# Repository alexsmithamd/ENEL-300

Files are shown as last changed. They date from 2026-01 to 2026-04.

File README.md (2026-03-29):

# ENEL-300
ENEL 300 Project Repo

This github repo will be used as the home of all project components. Code, CAD, general design work will be documented and stored here as well as one drive. 

### Guidelines
- Each module's directory contains a `pcb_design`, `print_3d_files`, and a `stm_code` sub-directory. Please organize your module's respective files in the correct directory. 

- The `print_3d_files` is NOT to be used for CAD files, but rather as an easy way to share STLs and slicer files so that we can effectively share the print workload amongst ourselves.

- **Avoid working in the same directory or on the same files as someone else - at the same time!!!** 
<br>
This can create "merge conflicts" which can be difficult to resolve.

Each module directory contains a `README.md` file. I would highly recommend putting **technical** documentation for your module in that file as it simplifies our workflow for everyone. Instead of having to look in OneDrive, one simply needs to do a `git pull` command to get the latest work and documentation!

Only use OneDrive for **administrative** documentation.

### Editing Markdown (.md) Files
Markdown is similar to LaTeX. It has very simple syntax and is used everywhere. **For editing, I would recommend VsCode with the following extension installed:**

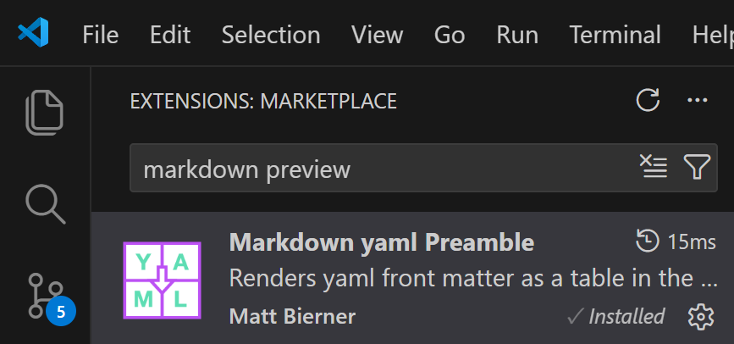
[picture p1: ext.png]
Optional title

<br>
This gives you the ability to edit and live preview your work as shown below:
<br>
<br>
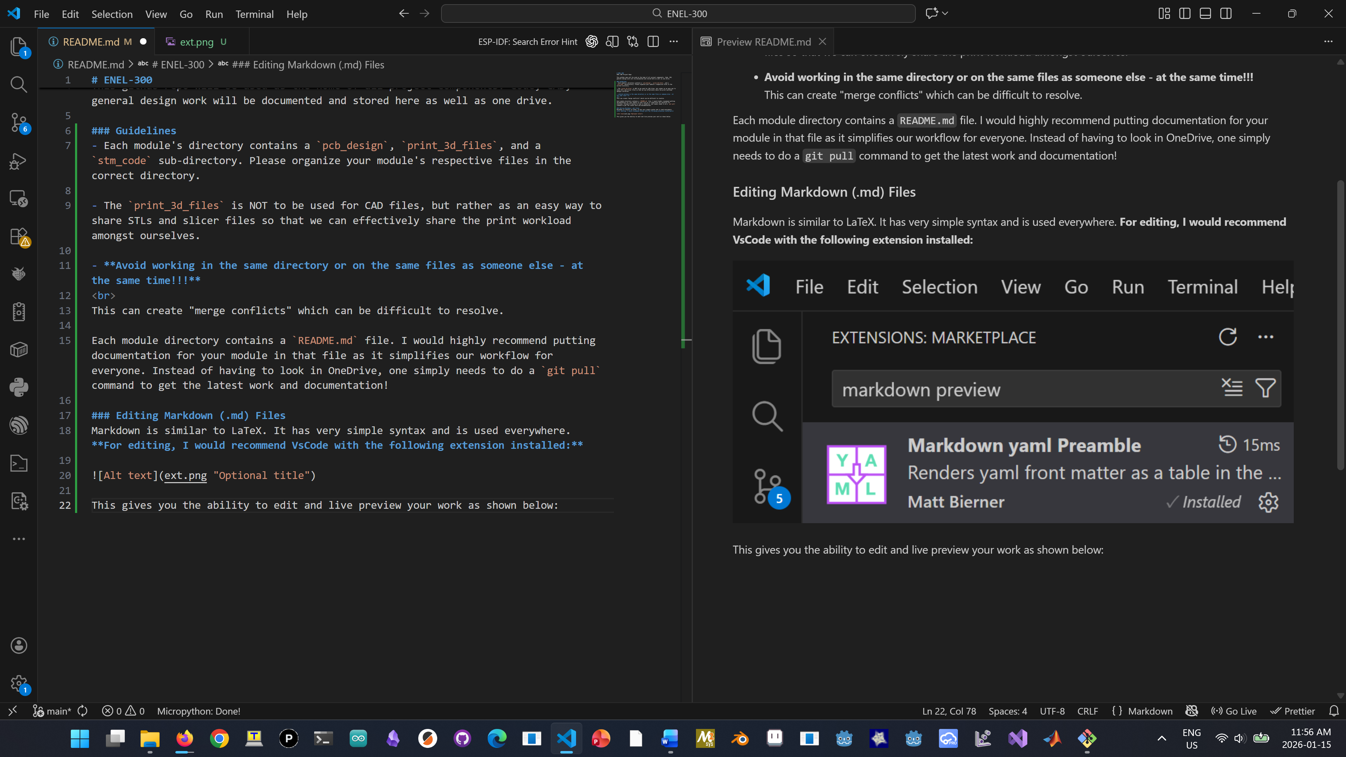
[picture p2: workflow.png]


### **To open the preview:** `Ctrl + Shift + P` then type `Markdown: Open Preview`

Drag the preview tab to the right pane and viola!

### Branches
Branches allow you to work on your own module without messing up somebody else's work. Changes you make in your own branch will NOT affect work done in another branch. Overtime, we will merge everyone's changes into the `main` branch. **DO NOT directly edit your work in the main branch.**  *The main branch is supposed to be the "working" version.* The division of a project into branches is unavoidable in industry.

I have created branches for each module.

1. Switching between branches<br>`git checkout main` -- switch to the main branch<br>`git checkout controller_board` -- switch to the controller_board branch

Commits and pushes will only apply to your respective branch. 

1. To view the current branch you are in
<br>`git branch`

### Pushing, Pulling, Adding, Committing
NOTE: A commit is like a snapshot of your project. You can revert your project back to any previous commits.
<br>
1. Whenever you want to work on the project, first sync your local repo with the remote repo (the one on GitHub):
<br>`git pull`

2. Before you plan to make major changes or upload your changes, *especially ones that may break your code:*
<br>`git add -A`
<br>`git commit -m "What ever message you want in these quotes"`

3. Uploading the latest commit<br>`git push`

<br>`git checkout -b controller_board origin/controller_board`

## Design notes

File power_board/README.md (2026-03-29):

# ENEL-300
### Power Board

# git
# Note

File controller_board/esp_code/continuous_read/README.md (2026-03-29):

<!-- @import "[TOC]" {cmd="toc" depthFrom=1 depthTo=6 orderedList=false} -->
| Supported Targets | ESP32 | ESP32-C3 | ESP32-C5 | ESP32-C6 | ESP32-C61 | ESP32-H2 | ESP32-P4 | ESP32-S2 | ESP32-S3 |
| --- | ----- | --- | --- | --- | --- | --- | --- | --- | --- |

# ADC DMA Example

(See the README.md file in the upper level 'examples' directory for more information about examples.)

This example shows how to use ADC Continuous Read Mode (DMA Mode) to read from GPIO pins via on-chip ADC module(s).

## How to use example

### Hardware Required

* A development board with ESP32, ESP32-S and ESP32-C SoC
* A USB cable for power supply and programming

Please refer to the `channel` array defined in `adc_dma_example_main.c`. These GPIOs should be connected to voltage sources (0 ~ 3.3V). If other ADC unit(s) / channel(s) are selected in your application,
feel free to modify these definitions.

### Configure the project

```
idf.py menuconfig
```

### Build and Flash

Build the project and flash it to the board, then run monitor tool to view serial output:

```
idf.py -p PORT flash monitor
```

(To exit the serial monitor, type ``Ctrl-]``.)

See the Getting Started Guide for full steps to configure and use ESP-IDF to build projects.

## Example Output

Running this example, you will see the following log output on the serial monitor:
```
I (367) EXAMPLE: adc_pattern[0].atten is :0
I (377) EXAMPLE: adc_pattern[0].channel is :2
I (377) EXAMPLE: adc_pattern[0].unit is :0
I (387) EXAMPLE: adc_pattern[1].atten is :0
I (387) EXAMPLE: adc_pattern[1].channel is :3
I (397) EXAMPLE: adc_pattern[1].unit is :0
I (397) gpio: GPIO[3]| InputEn: 0| OutputEn: 0| OpenDrain: 0| Pullup: 0| Pulldown: 0| Intr:0
I (407) gpio: GPIO[4]| InputEn: 0| OutputEn: 0| OpenDrain: 0| Pullup: 0| Pulldown: 0| Intr:0
I (417) TASK: ret is 0, ret_num is 256
I (427) EXAMPLE: Unit: ADC-1, Channel: 2, Value: 819
I (427) EXAMPLE: Unit: ADC-1, Channel: 3, Value: 7b9
I (437) EXAMPLE: Unit: ADC-1, Channel: 2, Value: 7ab
I (437) EXAMPLE: Unit: ADC-1, Channel: 3, Value: 74b
I (447) EXAMPLE: Unit: ADC-1, Channel: 2, Value: 74d
I (447) EXAMPLE: Unit: ADC-1, Channel: 3, Value: 6e5
I (457) EXAMPLE: Unit: ADC-1, Channel: 2, Value: 6ee
I (467) EXAMPLE: Unit: ADC-1, Channel: 3, Value: 680
I (467) EXAMPLE: Unit: ADC-1, Channel: 2, Value: 69a
I (477) EXAMPLE: Unit: ADC-1, Channel: 3, Value: 62f
...
```

## Troubleshooting

* program upload failure

    * Hardware connection is not correct: run `idf.py -p PORT monitor`, and reboot your board to see if there are any output logs.
    * The baud rate for downloading is too high: lower your baud rate in the `menuconfig` menu, and try again.

For any technical queries, please open an [issue](https://github.com/espressif/esp-idf/issues) on GitHub. We will get back to you soon.

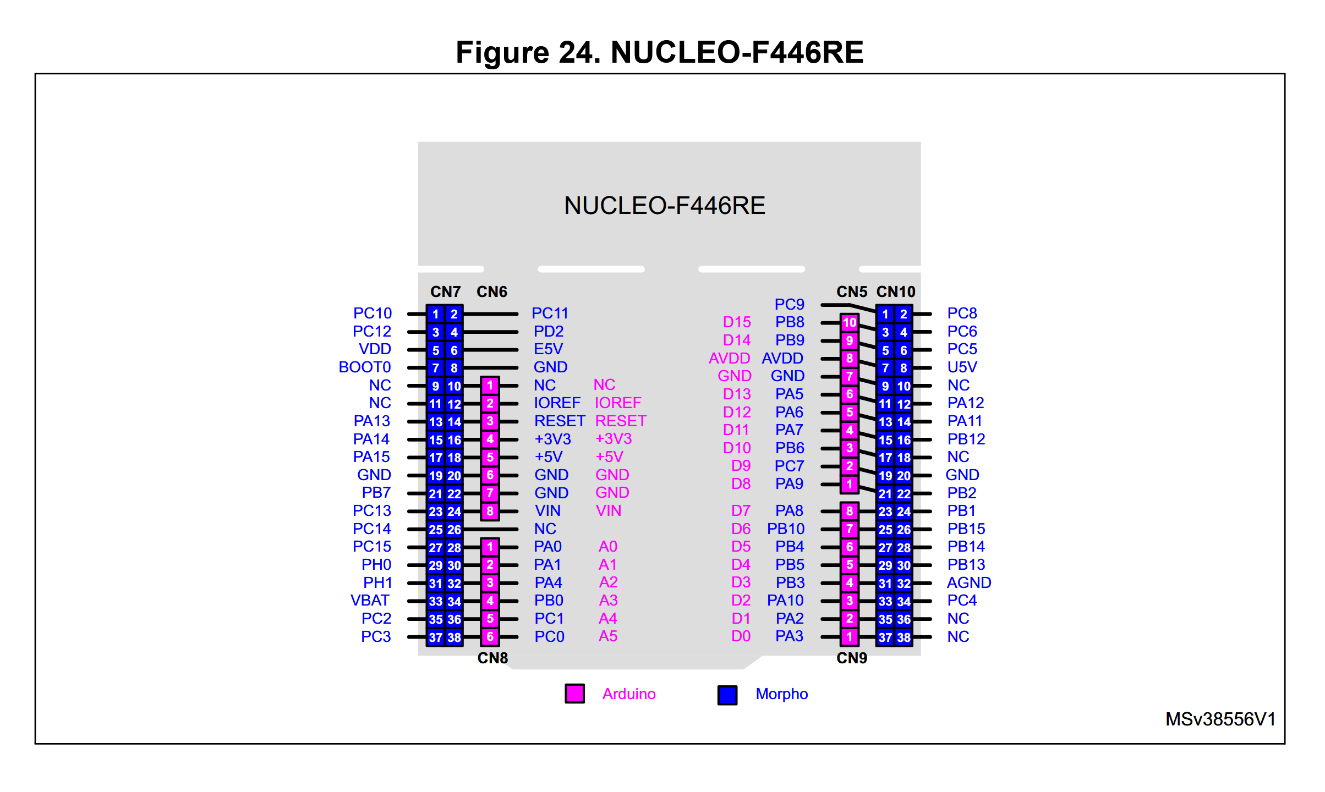
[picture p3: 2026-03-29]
controller_board/stm_board_pinout.png

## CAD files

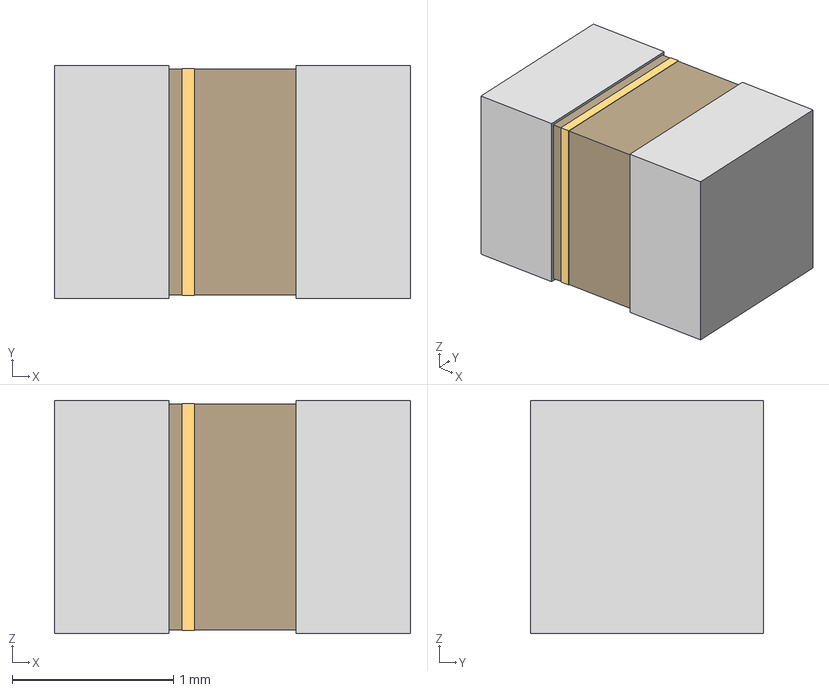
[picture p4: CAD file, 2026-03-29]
power_board/pcb_design/component_downloads/GRM21BR61E226ME44L/Altium/GRM21BR61E226ME44L/CAP_GRM21_MUR.step
2.21 x 1.45 x 1.45 mm

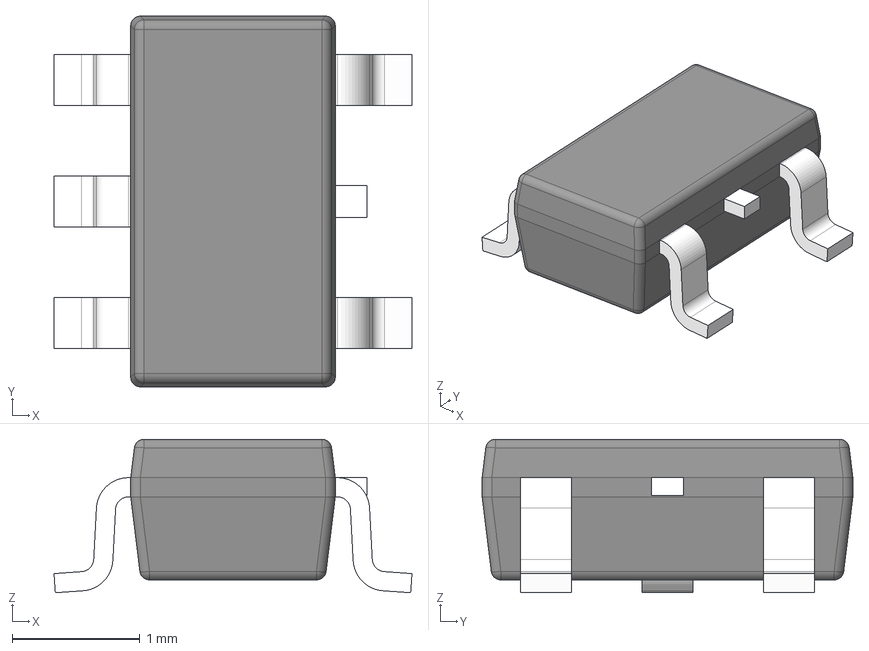
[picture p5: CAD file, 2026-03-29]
power_board/pcb_design/component_downloads/ul_TLV75733PDBVR/DBV0005A.stp
2.80 x 2.90 x 1.20 mm
BODY-SOT
LEAD-SOT x 5
LEAD-DUMMY

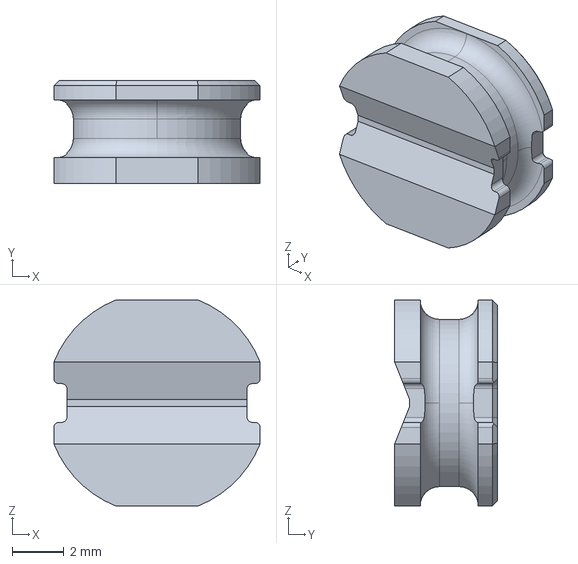
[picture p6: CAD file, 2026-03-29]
power_board/pcb_design/component_downloads/SRN8040_3R3Y/7435157.stp
8.00 x 4.00 x 8.00 mm

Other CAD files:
power_board/pcb_design/component_downloads/GRM21BR61E226ME44L/CAP_GRM21_MUR.step

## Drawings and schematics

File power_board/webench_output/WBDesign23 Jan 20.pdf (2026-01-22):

## WEBENCH ® Design Report

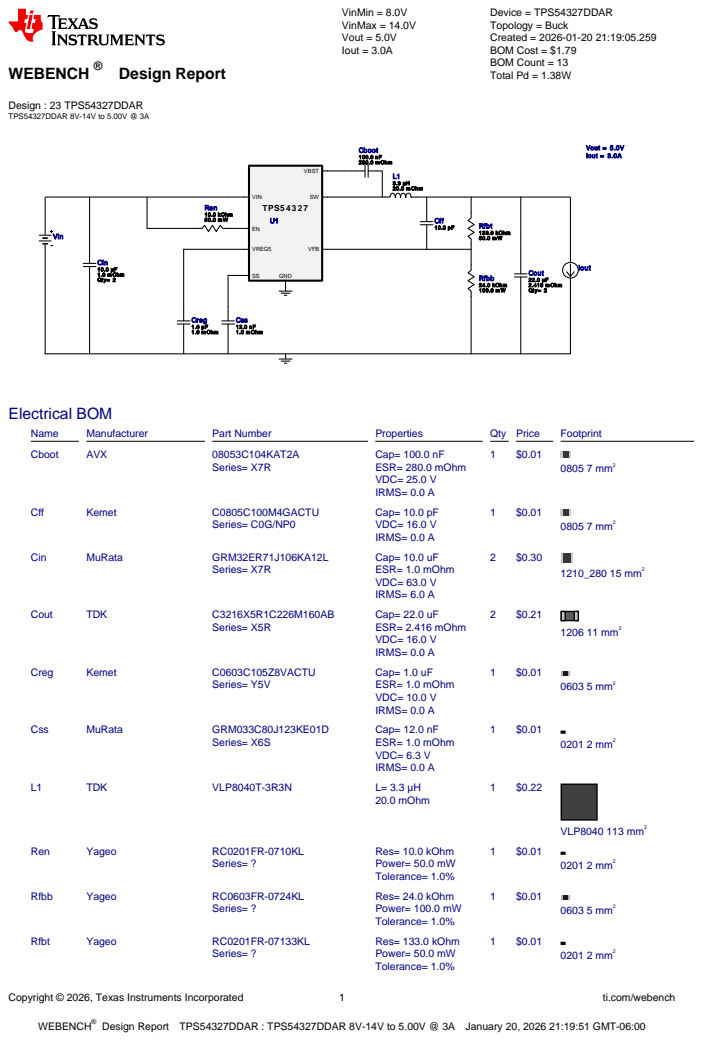
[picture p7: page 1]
Copyright © 2026, Texas Instruments Incorporated; ti.com/webench; WEBENCH®; Design : 23 TPS54327DDAR TPS54327DDAR 8V-14V to 5.00V @ 3A; VinMin = 8.0V VinMax = 14.0V Vout = 5.0V Iout = 3.0A; Device = TPS54327DDAR Topology = Buck Created = 2026-01-20 21:19:05.259 BOM Cost = $1.79 BOM Count = 13 Total Pd = 1.38W; Rfbb 24.0 kOhm 100.0 m W; Cout 22.0 µF 2.416 m Ohm Qty= 2; Css 12.0 nF 1.0 m Ohm; Ren 10.0 kOhm 50.0 m W; Creg 1.0 µF 1.0 m Ohm; Vout = 5.0V Iout = 3.0A Cboot 100.0 nF 280.0 m Ohm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

Design Report TPS54327DDAR : TPS54327DDAR 8V-14V to 5.00V @ 3A January 20, 2026 21:19:51 GMT-06:00

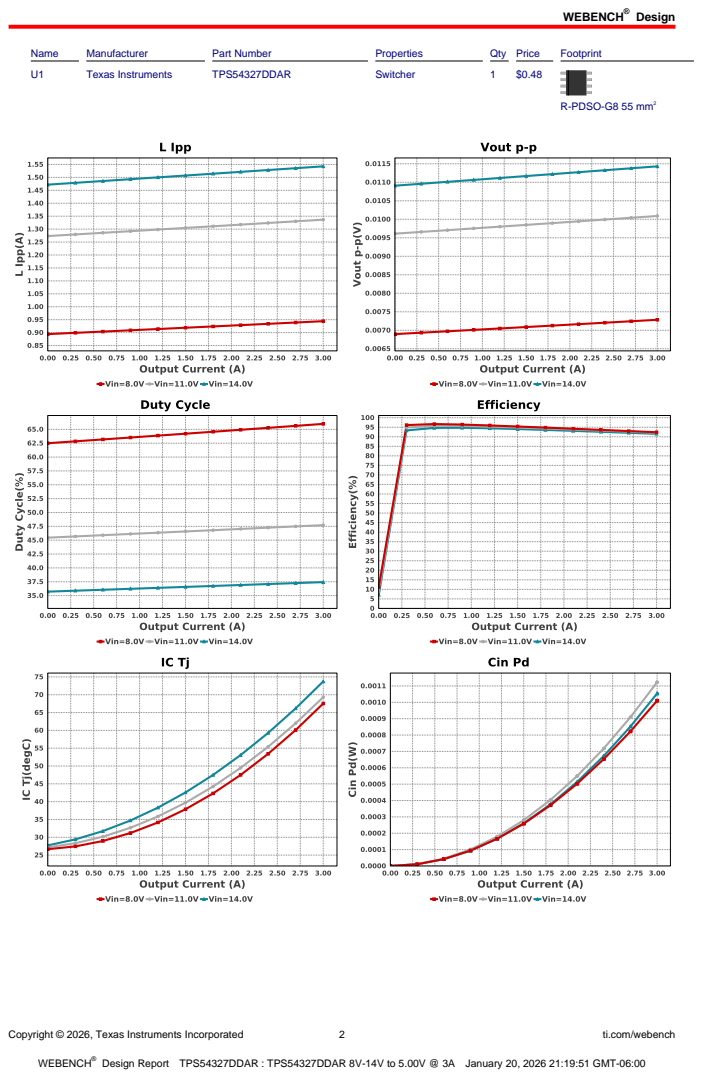
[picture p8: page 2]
Design; Copyright © 2026, Texas Instruments Incorporated; ti.com/webench; Name; Manufacturer; Part Number; Properties; Qty Price; Footprint; Texas Instruments; TPS54327DDAR; Switcher; R-PDSO-G8 55 mm²

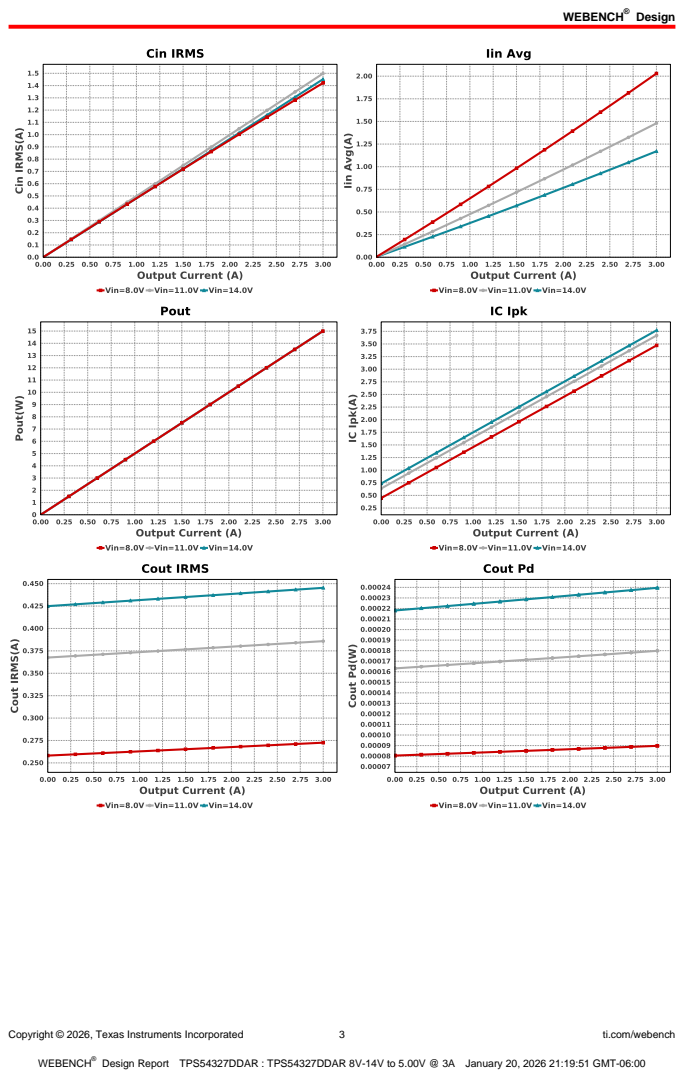
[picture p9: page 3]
Copyright © 2026, Texas Instruments Incorporated; ti.com/webench

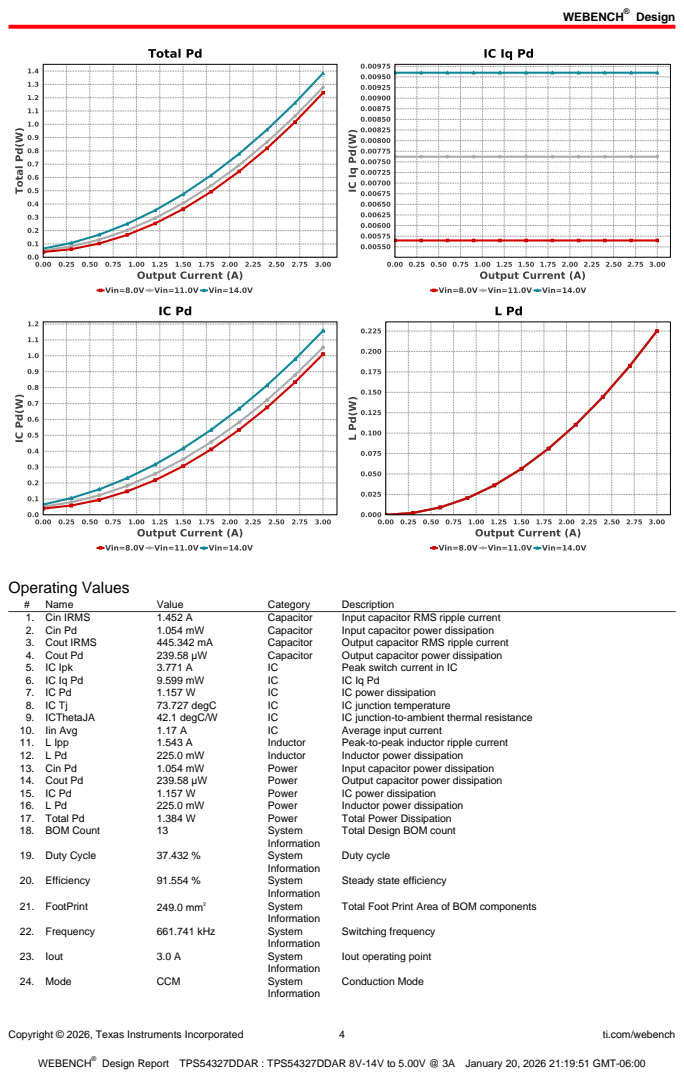
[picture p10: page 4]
Copyright © 2026, Texas Instruments Incorporated; ti.com/webench; Operating Values; Name; Value; Category; Description; 1. Cin IRMS; Capacitor; Input capacitor RMS ripple current; 2. Cin Pd; Input capacitor power dissipation; 3. Cout IRMS; Output capacitor RMS ripple current; 4. Cout Pd; Output capacitor power dissipation; 5. IC Ipk; Peak switch current in IC; IC power dissipation; 73.727 degC; IC junction temperature; 9. ICThetaJA; 42.1 degC/W; IC junction-to-ambient thermal resistance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

Total Design BOM count

Steady state efficiency

Total Foot Print Area of BOM components

Iout operating point

Copyright © 2026, Texas Instruments Incorporated | 5 | ti.com/webench
# | Name | Value | Category | Description

25. Pout | 15.0 W | System
| | | Information | Total output power
26. Total BOM | $1.79 | System
| | | Information | Total BOM Cost
27. Vin | 14.0 V | System
| | | Information | Vin operating point
28. Vout | 5.0 V | System
| | | Information | Operational Output Voltage
29. Vout Actual | 5.004 V | System
| | | Information | Vout Actual calculated based on selected voltage divider resistors
30. Vout Tolerance | 3.573 % | System
| | | Information | Vout Tolerance based on IC Tolerance (no load) and voltage divider resistors if applicable
31. Vout p-p | 11.431 mV | System
| | | Information | Peak-to-peak output ripple voltage

## Design Inputs

Name | Value | Description
Iout | 3.0 | Maximum Output Current
SoftStart | 5.0 ms | Soft Start Time (ms)
VinMax | 14.0 | Maximum input voltage
VinMin | 8.0 | Minimum input voltage
Vout | 5.0 | Output Voltage
| base_pn | | TPS54327 | Base Product Number
source | DC | Input Source Type
Ta | 25.0 | Ambient temperature


Copyright © 2026, Texas Instruments Incorporated | 6 | ti.com/webench

## Assembly

## Component Testing

Some published data on components in datasheets such as Capacitor ESR and Inductor DC resistance is based on conservative values that will guarantee that the components always exceed the specification. For design purposes it is usually better to work with typical values. Since this data is not always available it is a good practice to measure the Capacitance and ESR values of Cin and Cout, and the inductance and DC resistance of L1 before assembly of the board. Any large discrepancies in values should be electrically simulated in WEBENCH to check for instabilities and thermally simulated in WebTHERM to make sure critical temperatures are not exceeded.

## Soldering Component to Board

If board assembly is done in house it is best to tack down one terminal of a component on the board then solder the other terminal. For surface mount parts with large tabs, such as the DPAK, the tab on the back of the package should be pre-tinned with solder, then tacked into place by one of the pins. To solder the tab town to the board place the iron down on the board while resting against the tab, heating both surfaces simultaneously. Apply light pressure to the top of the plastic case until the solder flows around the part and the part is flush with the PCB. If the solder is not flowing around the board you may need a higher wattage iron (generally 25W to 30W is enough).
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

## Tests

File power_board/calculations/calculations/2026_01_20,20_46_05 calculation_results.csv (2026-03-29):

name | values
soft start T | 5.049
top resistor R | 122344.44444444444
cap rms I | 0.4016815416439882
L pk-pk I | 1.3914656771799627
L max pk I | 3.6957328385899815
L rms I | 3.0267718878200074

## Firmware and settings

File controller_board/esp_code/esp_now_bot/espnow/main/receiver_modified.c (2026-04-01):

/* ESPNOW Example

   This example code is in the Public Domain (or CC0 licensed, at your option.)

   Unless required by applicable law or agreed to in writing, this
   software is distributed on an "AS IS" BASIS, WITHOUT WARRANTIES OR
   CONDITIONS OF ANY KIND, either express or implied.
*/

/*
   This example shows how to use ESPNOW.
   Prepare two device, one for sending ESPNOW data and another for receiving
   ESPNOW data.
*/
#include <stdlib.h>
#include <math.h>
#include <time.h>
#include <complex.h>
#include <string.h>
#include <assert.h>
#include "freertos/FreeRTOS.h"
#include "freertos/semphr.h"
#include "freertos/timers.h"
#include "nvs_flash.h"
#include "esp_random.h"
#include "esp_event.h"
#include "esp_netif.h"
#include "esp_wifi.h"
#include "esp_log.h"
#include "esp_mac.h"
#include "esp_now.h"
#include "esp_crc.h"
#include "espnow_example.h"


#include "esp_timer.h"
#include "driver/gpio.h"
#include <driver/ledc.h>

#define L_Y_OFFSET 1.56
#define R_X_OFFSET 1.59

// these are the direction pins
#define IN1 GPIO_NUM_7
#define IN2 GPIO_NUM_6
#define IN3 GPIO_NUM_5
#define IN4 GPIO_NUM_4


#define PWM_1_CHANNEL LEDC_CHANNEL_0
#define PWM_2_CHANNEL LEDC_CHANNEL_1
#define PWM_3_CHANNEL LEDC_CHANNEL_2
#define PWM_4_CHANNEL LEDC_CHANNEL_3

         
#define LEDC_CHANNEL LEDC_CHANNEL_0
#define LEDC_TIMER LEDC_TIMER_0
#define LEDC_MODE LEDC_LOW_SPEED_MODE
#define LEDC_DUTY_RES LEDC_TIMER_10_BIT // 10-bit resolution (0-1023)
#define LEDC_FREQUENCY 3000   

#define US_TRIG_PIN   GPIO_NUM_17
#define US_ECHO_PIN   GPIO_NUM_18

//  Tuning knobs 
#define SOUND_CM_PER_US  0.0343f
#define PULSE_ON_US    8//70//20//1            // ms coil is at high state
#define PULSE_OFF_US   14//130//80            // ms coil is LOW state
#define SAMPLES_PER_MEAS  400//200        // more samples = less noise, slower response based off mapleaf config
// timeouts
#define ECHO_RISE_TIMEOUT_US   50000   // 30 ms (covers > 5m, but safe)
#define ECHO_FALL_TIMEOUT_US   50000
#define BASELINE_MS    1500//1500          // baseline averaging time on boot
#define THRESHOLD      18//10            // ADC counts; adjust after you see readings

#define HEADLIGHT_GPIO GPIO_NUM_10
#define METAL_DETECT GPIO_NUM_11

int trim_r = 0;
int trim_l = 0;

typedef struct {
    float raw[4];
} adc_snap_t;

adc_snap_t adc_struct = {{-1.0, -1.0, -1.0, -1.0}};

static float g_ultrasonic_cm = -1.0f;
static portMUX_TYPE g_ultrasonic_mux = portMUX_INITIALIZER_UNLOCKED;

#define ESPNOW_MAXDELAY 512

static const char *TAG = "espnow_example";

static QueueHandle_t s_example_espnow_queue = NULL;

// mac address of the master <-_-> dc:b4:d9:09:f9:80
static uint8_t s_peer_mac[ESP_NOW_ETH_ALEN] = { 0xDC, 0xB4, 0xD9, 0x0b, 0x64, 0x5c };
static uint8_t s_example_broadcast_mac[ESP_NOW_ETH_ALEN] = { 0xDC, 0xB4, 0xD9, 0x0b, 0x64, 0x5c };
static uint16_t s_example_espnow_seq[EXAMPLE_ESPNOW_DATA_MAX] = { 0, 0 };

static void example_espnow_deinit(example_espnow_send_param_t *send_param);


int map(double x, double in_min, double in_max, int out_min, int out_max) {
  return (x - in_min) * (out_max - out_min) / (in_max - in_min) + out_min;
}

// ultrasonic code

static void ultrasonic_init(void) {
    gpio_reset_pin(US_TRIG_PIN);
    gpio_set_direction(US_TRIG_PIN, GPIO_MODE_OUTPUT);
    gpio_set_level(US_TRIG_PIN, 0);

    gpio_reset_pin(US_ECHO_PIN);
    gpio_set_direction(US_ECHO_PIN, GPIO_MODE_INPUT);
}

static int64_t pulse_in_us(gpio_num_t pin, int level, int64_t timeout_us) {
    int64_t start = esp_timer_get_time();
    while (gpio_get_level(pin) != level) {
        if ((esp_timer_get_time() - start) > timeout_us) return -1;
    }
    int64_t t0 = esp_timer_get_time();
    while (gpio_get_level(pin) == level) {
        if ((esp_timer_get_time() - t0) > timeout_us) return -1;
    }
    return esp_timer_get_time() - t0;
}

static float ultrasonic_read_cm(void) {

    // Ensure low
    gpio_set_level(US_TRIG_PIN, 0);
    esp_rom_delay_us(2);

    // 10us trigger pulse
    gpio_set_level(US_TRIG_PIN, 1);
    esp_rom_delay_us(10);
    gpio_set_level(US_TRIG_PIN, 0);

    // Wait for echo HIGH then measure HIGH width
    // First wait for rising edge (echo goes high)
    int64_t start = esp_timer_get_time();
    while (gpio_get_level(US_ECHO_PIN) == 0) {
        if (esp_timer_get_time() - start > ECHO_RISE_TIMEOUT_US) return -1.0f;
    }

    // Now measure high pulse width
    int64_t width = pulse_in_us(US_ECHO_PIN, 1, ECHO_FALL_TIMEOUT_US);
    if (width < 0) return -1.0f;

    // distance = (time * speed) / 2
    float cm = (width * SOUND_CM_PER_US) / 2.0f;
    return cm;
}


/* WiFi should start before using ESPNOW */
static void example_wifi_init(void)
{
    ESP_ERROR_CHECK(esp_netif_init());
    ESP_ERROR_CHECK(esp_event_loop_create_default());
    wifi_init_config_t cfg = WIFI_INIT_CONFIG_DEFAULT();
    ESP_ERROR_CHECK( esp_wifi_init(&cfg) );
    ESP_ERROR_CHECK( esp_wifi_set_storage(WIFI_STORAGE_RAM) );
    ESP_ERROR_CHECK( esp_wifi_set_mode(ESPNOW_WIFI_MODE) );
    ESP_ERROR_CHECK( esp_wifi_start());
    ESP_ERROR_CHECK( esp_wifi_set_channel(CONFIG_ESPNOW_CHANNEL, WIFI_SECOND_CHAN_NONE));

#if CONFIG_ESPNOW_ENABLE_LONG_RANGE
    ESP_ERROR_CHECK( esp_wifi_set_protocol(ESPNOW_WIFI_IF, WIFI_PROTOCOL_11B|WIFI_PROTOCOL_11G|WIFI_PROTOCOL_11N|WIFI_PROTOCOL_LR) );
#endif
}

/* ESPNOW sending or receiving callback function is called in WiFi task.
 * Users should not do lengthy operations from this task. Instead, post
 * necessary data to a queue and handle it from a lower priority task. */
static void example_espnow_send_cb(const esp_now_send_info_t *tx_info, esp_now_send_status_t status)
{
    example_espnow_event_t evt;
    example_espnow_event_send_cb_t *send_cb = &evt.info.send_cb;

    if (tx_info == NULL) {
        ESP_LOGE(TAG, "Send cb arg error");
        return;
    }

    evt.id = EXAMPLE_ESPNOW_SEND_CB;
    memcpy(send_cb->mac_addr, tx_info->des_addr, ESP_NOW_ETH_ALEN);
    send_cb->status = status;
    if (xQueueSend(s_example_espnow_queue, &evt, ESPNOW_MAXDELAY) != pdTRUE) {
        ESP_LOGW(TAG, "Send send queue fail");
    }
}

static void example_espnow_recv_cb(const esp_now_recv_info_t *recv_info, const uint8_t *data, int len)
{
    example_espnow_event_t evt;
    example_espnow_event_recv_cb_t *recv_cb = &evt.info.recv_cb;
    uint8_t * mac_addr = recv_info->src_addr;
    uint8_t * des_addr = recv_info->des_addr;

    if (mac_addr == NULL || data == NULL || len <= 0) {
        ESP_LOGE(TAG, "Receive cb arg error");
        return;
    }

    if (IS_BROADCAST_ADDR(des_addr)) {
        /* If added a peer with encryption before, the receive packets may be
         * encrypted as peer-to-peer message or unencrypted over the broadcast channel.
         * Users can check the destination address to distinguish it.
         */
        ESP_LOGD(TAG, "Receive broadcast ESPNOW data");
    } else {
        ESP_LOGD(TAG, "Receive unicast ESPNOW data");
    }

    evt.id = EXAMPLE_ESPNOW_RECV_CB;
    memcpy(recv_cb->mac_addr, mac_addr, ESP_NOW_ETH_ALEN);
    recv_cb->data = malloc(len);
    if (recv_cb->data == NULL) {
        ESP_LOGE(TAG, "Malloc receive data fail");
        return;
    }
    memcpy(recv_cb->data, data, len);
    recv_cb->data_len = len;
    if (xQueueSend(s_example_espnow_queue, &evt, ESPNOW_MAXDELAY) != pdTRUE) {
        ESP_LOGW(TAG, "Send receive queue fail");
        free(recv_cb->data);
    }
}

/* Parse received ESPNOW data. */

// lock
static portMUX_TYPE adc_struct_mux = portMUX_INITIALIZER_UNLOCKED; 

int light_state = 0;

int example_espnow_data_parse(uint8_t *data, uint16_t data_len, uint8_t *state, uint16_t *seq, uint32_t *magic)
{
    example_espnow_data_t *buf = (example_espnow_data_t *)data;
    uint16_t crc, crc_cal = 0;

    if (data_len < sizeof(example_espnow_data_t)) {
        ESP_LOGE(TAG, "Receive ESPNOW data too short, len:%d", data_len);
        return -1;
    }

    *state = buf->state;
    *seq = buf->seq_num;
    *magic = buf->magic;
    crc = buf->crc;
    buf->crc = 0;
    crc_cal = esp_crc16_le(UINT16_MAX, (uint8_t const *)buf, data_len);

    float temp_arr [7] = {-1.0, -1.0, -1.0, -1.0, -1.0, -1.0, -1.0}; // last two are trim params
    memcpy(temp_arr, buf->payload, sizeof(temp_arr));
    light_state = (int)temp_arr[4];
    trim_l = (int)temp_arr[5];
    trim_r = (int)temp_arr[6];

    gpio_set_level(HEADLIGHT_GPIO, light_state);

    float control_data[4] = {-1.0, -1.0, -1.0, -1.0};
    memcpy(control_data, temp_arr, sizeof(temp_arr) - 3); // copy the first four elements
   
    adc_snap_t temp = {{-1.0, -1.0, -1.0, -1.0}}; // kind of forgot what the purpose of this is
    memcpy(temp.raw, control_data, sizeof(control_data));

    taskENTER_CRITICAL(&adc_struct_mux);
        adc_struct = temp;
    taskEXIT_CRITICAL(&adc_struct_mux);

    //ESP_LOGI("RECIEVED ADC DATA", "%f %f %f %f", temp.raw[0], temp.raw[1], temp.raw[2], temp.raw[3]);

    if (crc_cal == crc) {
        return buf->type;
    }

    return -1;
}
void example_espnow_data_prepare(example_espnow_send_param_t *send_param)
{
    example_espnow_data_t *buf = (example_espnow_data_t *)send_param->buffer;

    assert(send_param->len >= sizeof(example_espnow_data_t));

    buf->type = IS_BROADCAST_ADDR(send_param->dest_mac) ? EXAMPLE_ESPNOW_DATA_BROADCAST : EXAMPLE_ESPNOW_DATA_UNICAST;
    buf->state = send_param->state;
    buf->seq_num = s_example_espnow_seq[buf->type]++;
    buf->crc = 0;
    buf->magic = send_param->magic;

    // Clear payload first
    memset(buf->payload, 0, send_param->len - sizeof(example_espnow_data_t));

    // Copy ultrasonic reading into payload
    float ultrasonic_cm;
    taskENTER_CRITICAL(&g_ultrasonic_mux);
    ultrasonic_cm = g_ultrasonic_cm;
    taskEXIT_CRITICAL(&g_ultrasonic_mux);

    int metal_state = gpio_get_level(METAL_DETECT);

    float combined_pay[2] = {-1.0, -1.0};
    combined_pay[0] = ultrasonic_cm; 
    combined_pay[1] = (float)metal_state;

    memcpy(buf->payload, combined_pay, sizeof(combined_pay));

    buf->crc = esp_crc16_le(UINT16_MAX, (uint8_t const *)buf, send_param->len);
}




static void ultrasonic_tx_task(void *arg)
{
    example_espnow_send_param_t *send_param = (example_espnow_send_param_t *)arg;
    assert(send_param != NULL);

    ESP_LOGI(TAG, "Ultrasonic TX task started");

    while (1) {
        example_espnow_data_prepare(send_param);
        esp_err_t err = esp_now_send(send_param->dest_mac, send_param->buffer, send_param->len);
        if (err != ESP_OK) {
            ESP_LOGW(TAG, "ultrasonic esp_now_send failed: %s", esp_err_to_name(err));
        }
        vTaskDelay(pdMS_TO_TICKS(100));
    }
}


static void example_espnow_task(void *pvParameter)
{
    example_espnow_event_t evt;
    uint8_t recv_state = 0;
    uint16_t recv_seq = 0;
    uint32_t recv_magic = 0;
    int ret;

    (void)pvParameter;
    ESP_LOGI(TAG, "Robot RX task started");

    while (xQueueReceive(s_example_espnow_queue, &evt, portMAX_DELAY) == pdTRUE) {

        switch (evt.id) {
            case EXAMPLE_ESPNOW_SEND_CB:
            {
                example_espnow_event_send_cb_t *send_cb = &evt.info.send_cb;
                ESP_LOGD(TAG, "Send callback from " MACSTR ", status=%d",
                         MAC2STR(send_cb->mac_addr), send_cb->status);
                break;
            }

            case EXAMPLE_ESPNOW_RECV_CB:
            {
                example_espnow_event_recv_cb_t *recv_cb = &evt.info.recv_cb;

                ret = example_espnow_data_parse(recv_cb->data, recv_cb->data_len,
                                                &recv_state, &recv_seq, &recv_magic);

                if (ret == EXAMPLE_ESPNOW_DATA_UNICAST) {
                    ESP_LOGD(TAG, "Received unicast from " MACSTR ", len=%d",
                             MAC2STR(recv_cb->mac_addr), recv_cb->data_len);
                } else if (ret < 0) {
                    ESP_LOGW(TAG, "Receive parse error from " MACSTR, MAC2STR(recv_cb->mac_addr));
                }

                free(recv_cb->data);
                break;

            }
            default:
                ESP_LOGE(TAG, "Callback type error: %d", evt.id);
                break;
        }
    }
}

static esp_err_t example_espnow_init(void)
{
    example_espnow_send_param_t *send_param;

    s_example_espnow_queue = xQueueCreate(ESPNOW_QUEUE_SIZE, sizeof(example_espnow_event_t));
    if (s_example_espnow_queue == NULL) {
        ESP_LOGE(TAG, "Create queue fail");
        return ESP_FAIL;
    }

    /* Initialize ESPNOW and register sending and receiving callback function. */
    ESP_ERROR_CHECK( esp_now_init() );
    ESP_ERROR_CHECK( esp_now_register_send_cb(example_espnow_send_cb) );
    ESP_ERROR_CHECK( esp_now_register_recv_cb(example_espnow_recv_cb) );
#if CONFIG_ESPNOW_ENABLE_POWER_SAVE
    ESP_ERROR_CHECK( esp_now_set_wake_window(CONFIG_ESPNOW_WAKE_WINDOW) );
    ESP_ERROR_CHECK( esp_wifi_connectionless_module_set_wake_interval(CONFIG_ESPNOW_WAKE_INTERVAL) );
#endif
    /* Set primary master key. */
    ESP_ERROR_CHECK( esp_now_set_pmk((uint8_t *)CONFIG_ESPNOW_PMK) );

    /* Add broadcast peer information to peer list. */
    esp_now_peer_info_t *peer = malloc(sizeof(esp_now_peer_info_t));
    if (peer == NULL) {
        ESP_LOGE(TAG, "Malloc peer information fail");
        vQueueDelete(s_example_espnow_queue);
        s_example_espnow_queue = NULL;
        esp_now_deinit();
        return ESP_FAIL;
    }
    memset(peer, 0, sizeof(esp_now_peer_info_t));
    peer->channel = CONFIG_ESPNOW_CHANNEL;
    peer->ifidx = ESPNOW_WIFI_IF;
    peer->encrypt = false;
    memcpy(peer->peer_addr, s_peer_mac, ESP_NOW_ETH_ALEN);
    ESP_ERROR_CHECK( esp_now_add_peer(peer) );
    free(peer);

    /* Initialize sending parameters. */
    send_param = malloc(sizeof(example_espnow_send_param_t));
    if (send_param == NULL) {
        ESP_LOGE(TAG, "Malloc send parameter fail");
        vQueueDelete(s_example_espnow_queue);
        s_example_espnow_queue = NULL;
        esp_now_deinit();
        return ESP_FAIL;
    }
    memset(send_param, 0, sizeof(example_espnow_send_param_t));
    send_param->unicast = true;
    send_param->broadcast = false;
    send_param->state = 0;
    send_param->magic = esp_random();
    send_param->count = CONFIG_ESPNOW_SEND_COUNT;
    send_param->delay = CONFIG_ESPNOW_SEND_DELAY;
    send_param->len = CONFIG_ESPNOW_SEND_LEN;
    send_param->buffer = malloc(CONFIG_ESPNOW_SEND_LEN);
    if (send_param->buffer == NULL) {
        ESP_LOGE(TAG, "Malloc send buffer fail");
        free(send_param);
        vQueueDelete(s_example_espnow_queue);
        s_example_espnow_queue = NULL;
        esp_now_deinit();
        return ESP_FAIL;
    }
    memcpy(send_param->dest_mac, s_peer_mac, ESP_NOW_ETH_ALEN);
    example_espnow_data_prepare(send_param);


    xTaskCreatePinnedToCore(example_espnow_task, "robot_rx_task", 4096, NULL, 6, NULL, 0);
    xTaskCreatePinnedToCore(ultrasonic_tx_task, "ultrasonic_tx_task", 4096, send_param, 6, NULL, 0);

    return ESP_OK;
}

static void example_espnow_deinit(example_espnow_send_param_t *send_param)
{
    free(send_param->buffer);
    free(send_param);
    vQueueDelete(s_example_espnow_queue);
    s_example_espnow_queue = NULL;
    esp_now_deinit();
}

static void configure_PWM(void){
    gpio_reset_pin(IN1);
    gpio_reset_pin(IN2);
    gpio_reset_pin(IN3);
    gpio_reset_pin(IN4);

    gpio_set_direction(IN1, GPIO_MODE_OUTPUT);
    gpio_set_direction(IN2, GPIO_MODE_OUTPUT);
    gpio_set_direction(IN3, GPIO_MODE_OUTPUT);
    gpio_set_direction(IN4, GPIO_MODE_OUTPUT);

    ledc_timer_config_t motora_timer = {
        .speed_mode = LEDC_MODE,
        .duty_resolution = LEDC_DUTY_RES,
        .timer_num = LEDC_TIMER,
        .freq_hz = LEDC_FREQUENCY
    };

    ledc_timer_config_t motorb_timer = {
        .speed_mode = LEDC_MODE,
        .duty_resolution = LEDC_DUTY_RES,
        .timer_num = LEDC_TIMER,
        .freq_hz = LEDC_FREQUENCY
    };

    ledc_timer_config_t motorc_timer = {
        .speed_mode = LEDC_MODE,
        .duty_resolution = LEDC_DUTY_RES,
        .timer_num = LEDC_TIMER,
        .freq_hz = LEDC_FREQUENCY
    };

    ledc_timer_config_t motord_timer = {
        .speed_mode = LEDC_MODE,
        .duty_resolution = LEDC_DUTY_RES,
        .timer_num = LEDC_TIMER,
        .freq_hz = LEDC_FREQUENCY
    };
    
    ledc_timer_config(&motora_timer);
    ledc_timer_config(&motorb_timer);
    ledc_timer_config(&motorc_timer);
    ledc_timer_config(&motord_timer);



    ledc_channel_config_t motora_channel = {
        .gpio_num = IN1,
        .speed_mode = LEDC_MODE,
        .channel = PWM_1_CHANNEL,
        .timer_sel = LEDC_TIMER,
        .duty = 0
    };

    ledc_channel_config_t motorb_channel = {
        .gpio_num = IN2,
        .speed_mode = LEDC_MODE,
        .channel = PWM_2_CHANNEL,
        .timer_sel = LEDC_TIMER,
        .duty = 0
    };

    ledc_channel_config_t motorc_channel = {
        .gpio_num = IN3,
        .speed_mode = LEDC_MODE,
        .channel = PWM_3_CHANNEL,
        .timer_sel = LEDC_TIMER,
        .duty = 0
    };

    ledc_channel_config_t motord_channel = {
        .gpio_num = IN4,
        .speed_mode = LEDC_MODE,
        .channel = PWM_4_CHANNEL,
        .timer_sel = LEDC_TIMER,
        .duty = 0
    };

    ledc_channel_config(&motora_channel);
    ledc_channel_config(&motorb_channel);
    ledc_channel_config(&motorc_channel);
    ledc_channel_config(&motord_channel);

    return;
}
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
void app_main(void)
{
    gpio_set_direction(GPIO_NUM_5, GPIO_MODE_OUTPUT);
    gpio_set_level(GPIO_NUM_5, 0);

    gpio_set_direction(GPIO_NUM_7, GPIO_MODE_OUTPUT);
    gpio_set_level(GPIO_NUM_7, 0);

    gpio_set_direction(METAL_DETECT, GPIO_MODE_INPUT);
    gpio_set_pull_mode(METAL_DETECT, GPIO_PULLDOWN_ENABLE);


    gpio_set_direction(HEADLIGHT_GPIO, GPIO_MODE_OUTPUT);
    gpio_set_level(HEADLIGHT_GPIO, 0);

    ultrasonic_init();
    configure_PWM();
    xTaskCreate(ultrasonic_task, "ultrasonic_task", 4096, NULL, 2, NULL);
    xTaskCreate(pwm_task, "pwm_task", 4096, &adc_struct, 5, NULL);
    //xTaskCreatePinnedToCore(pwm_task, "pwm_task", 4096, &adc_struct, 5, NULL, 1);

    // Initialize NVS
    esp_err_t ret = nvs_flash_init();
    if (ret == ESP_ERR_NVS_NO_FREE_PAGES || ret == ESP_ERR_NVS_NEW_VERSION_FOUND) {
        ESP_ERROR_CHECK( nvs_flash_erase() );
        ret = nvs_flash_init();
    }
    ESP_ERROR_CHECK( ret );

    example_wifi_init();
    example_espnow_init();

    
}

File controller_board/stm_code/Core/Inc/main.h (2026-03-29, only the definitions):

#define CE_Pin GPIO_PIN_7
#define CE_GPIO_Port GPIOC
#define IRQ_Pin GPIO_PIN_9
#define IRQ_GPIO_Port GPIOA
#define IRQ_EXTI_IRQn EXTI9_5_IRQn
#define SPI1_CSN_Pin GPIO_PIN_6
#define SPI1_CSN_GPIO_Port GPIOB

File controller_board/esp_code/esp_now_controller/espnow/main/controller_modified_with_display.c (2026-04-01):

/* ESPNOW Example

   This example code is in the Public Domain (or CC0 licensed, at your option.)

   Unless required by applicable law or agreed to in writing, this
   software is distributed on an "AS IS" BASIS, WITHOUT WARRANTIES OR
   CONDITIONS OF ANY KIND, either express or implied.
*/

/*
   This example shows how to use ESPNOW.
   Prepare two device, one for sending ESPNOW data and another for receiving
   ESPNOW data.
*/
#include <stdlib.h>
#include <time.h>
#include <string.h>
#include <assert.h>
#include <stdio.h>

int metal_detected = 0;
  
#include "freertos/FreeRTOS.h"
#include "freertos/semphr.h"
#include "freertos/timers.h"
#include "freertos/task.h"

#include "nvs_flash.h"
#include "esp_random.h"
#include "esp_event.h"
#include "esp_netif.h"
#include "esp_wifi.h"
#include "esp_log.h"
#include "esp_mac.h"
#include "esp_now.h"
#include "esp_crc.h"
#include "esp_timer.h"
#include "esp_err.h"

#include "driver/i2c.h"
#include "esp_lcd_panel_io.h"
#include "esp_lcd_panel_ops.h"
#include "esp_lvgl_port.h"
#include "lvgl.h"
#include "esp_lcd_panel_vendor.h"

#include "espnow_example.h"
#include "read_adc.h"
#include <driver/ledc.h>

#define BUZZER_PIN      GPIO_NUM_21
#define LEDC_TIMER      LEDC_TIMER_0
#define LEDC_MODE       LEDC_LOW_SPEED_MODE
#define LEDC_CHANNEL    LEDC_CHANNEL_0
#define LEDC_DUTY_RES   LEDC_TIMER_10_BIT // 1024 duty resolution
#define FREQ            (2000)            // 2 kHz sound

// isr code
#define BUTTON_GPIO GPIO_NUM_38
#define DEBOUNCE_DELAY_US 200000ULL

int trim_r = 0;
int trim_l = 0;

// trim ISRs

// trim_l isr
static volatile uint64_t last_isr_time_l = 0;
static volatile uint32_t counter_l = 0;
static QueueHandle_t button_queue_l;

uint32_t button_counter_l = 0;

static void IRAM_ATTR button_isr_l(void *arg) {
    uint64_t now = esp_timer_get_time(); // Get current time in microseconds
    // Check if debounce period has passed, then process the button press
    if (now - last_isr_time_l > DEBOUNCE_DELAY_US) {
        counter_l++;
        uint32_t cnt = counter_l;
        BaseType_t higher_priority_task_woken = pdFALSE;
        xQueueSendFromISR(button_queue_l, &cnt, &higher_priority_task_woken); // Send counter to queue from ISR
        last_isr_time_l = now;
        if (higher_priority_task_woken) {
            portYIELD_FROM_ISR();
        }
    }
}


// trim_r isr
static volatile uint64_t last_isr_time_r = 0;
static volatile uint32_t counter_r = 0;
static QueueHandle_t button_queue_r;

uint32_t button_counter_r = 0;

static void IRAM_ATTR button_isr_r(void *arg) {
    uint64_t now = esp_timer_get_time(); // Get current time in microseconds
    // Check if debounce period has passed, then process the button press
    if (now - last_isr_time_r > DEBOUNCE_DELAY_US) {
        counter_r++;
        uint32_t cnt = counter_r;
        BaseType_t higher_priority_task_woken = pdFALSE;
        xQueueSendFromISR(button_queue_r, &cnt, &higher_priority_task_woken); // Send counter to queue from ISR
        last_isr_time_r = now;
        if (higher_priority_task_woken) {
            portYIELD_FROM_ISR();
        }
    }
}



// headlight toggle ISR
static volatile uint64_t last_isr_time = 0;
static volatile uint32_t counter = 0;
static QueueHandle_t button_queue;

uint32_t button_counter;

//button isr
static void IRAM_ATTR button_isr(void *arg) {
    uint64_t now = esp_timer_get_time(); // Get current time in microseconds
    // Check if debounce period has passed, then process the button press
    if (now - last_isr_time > DEBOUNCE_DELAY_US) {
        counter++;
        uint32_t cnt = counter;
        BaseType_t higher_priority_task_woken = pdFALSE;
        xQueueSendFromISR(button_queue, &cnt, &higher_priority_task_woken); // Send counter to queue from ISR
        last_isr_time = now;
        if (higher_priority_task_woken) {
            portYIELD_FROM_ISR();
        }
    }
}


#define ESPNOW_MAXDELAY 512

static const char *TAG = "espnow_example";
static const char *DISP_TAG = "oled_display";

static QueueHandle_t s_example_espnow_queue = NULL;

// mac addr of the slave
static uint8_t s_example_broadcast_mac[ESP_NOW_ETH_ALEN] = { 0xDC, 0xB4, 0xD9, 0x09, 0xf9, 0x80 }; //dc:b4:d9:09:f9:80
static uint8_t s_peer_mac[ESP_NOW_ETH_ALEN] = { 0xDC, 0xB4, 0xD9, 0x09, 0xf9, 0x80 };
static uint16_t s_example_espnow_seq[EXAMPLE_ESPNOW_DATA_MAX] = { 0, 0 };

static void example_espnow_deinit(example_espnow_send_param_t *send_param);

typedef struct {
    float raw[4];
} adc_snap_t;

// OLED / LVGL configuration from the SSD1306 example
#define I2C_HOST                    0
#define EXAMPLE_LCD_PIXEL_CLOCK_HZ (128 * 64)
#define EXAMPLE_PIN_NUM_SDA         18
#define EXAMPLE_PIN_NUM_SCL         17
#define EXAMPLE_PIN_NUM_RST         -1
#define EXAMPLE_I2C_HW_ADDR         0x3C
#define EXAMPLE_LCD_H_RES           128
#define EXAMPLE_LCD_V_RES           64
#define EXAMPLE_LCD_CMD_BITS        8
#define EXAMPLE_LCD_PARAM_BITS      8



static lv_disp_t *s_disp = NULL;
static lv_obj_t *s_distance_label = NULL;
static lv_obj_t *s_detected_label = NULL;

// for locking the adc_struct between threads
static portMUX_TYPE adc_struct_mux = portMUX_INITIALIZER_UNLOCKED;
static portMUX_TYPE ultrasonic_mux = portMUX_INITIALIZER_UNLOCKED;

adc_snap_t adc_struct = {{-1.0, -1.0, -1.0, -1.0}}; // init as neg
static float g_ultrasonic_cm = -1.0f;

static void display_create_ui(lv_disp_t *disp)
{
    lv_obj_t *scr = lv_disp_get_scr_act(disp);

    s_distance_label = lv_label_create(scr);
    lv_label_set_text(s_distance_label, "Dist: -- cm");
    lv_obj_set_width(s_distance_label, EXAMPLE_LCD_H_RES);
    lv_obj_align(s_distance_label, LV_ALIGN_TOP_LEFT, 0, 0);

    s_detected_label = lv_label_create(scr);
    lv_label_set_text(s_detected_label, "Detected: NO");
    lv_obj_align(s_detected_label, LV_ALIGN_TOP_LEFT, 0, 20);
}

static void display_update_labels(float distance_cm)
{
    if (s_distance_label == NULL || s_detected_label == NULL) {
        return;
    }

    char line1[32];
    char line2[32];

    if (distance_cm < 0.0f) {
        snprintf(line1, sizeof(line1), "Dist: waiting...");
        snprintf(line2, sizeof(line2), "Detected: NO");
    } else {
        snprintf(line1, sizeof(line1), "Dist: %.2f cm", distance_cm);
        snprintf(line2, sizeof(line2), "Detected: %s", (distance_cm > 0.0f) ? "YES" : "NO");
    }

    lv_label_set_text(s_distance_label, line1);
    lv_label_set_text(s_detected_label, line2);
}
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

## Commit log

2026-01-17 Created the PCB Altium Project
    [power_board.PrjPcb, power_board_pcblib.PcbLib, power_board_schlib.SchLib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]
2026-01-17 Added more sheets to the project
    [buck_converter.SchDoc, ldo.SchDoc, over_voltage_protection.SchDoc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]
2026-01-18 created a basic STMcube project for the controller board
2026-01-19 Printing Calcualtion reuslts works
    [calculation_results.csv]
2026-01-20 added buck converter and ldo to the pcb
    [DBV0005A.stp, TLV75733PDBVR.PcbLib, TLV75733PDBVR.SchLib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]
2026-01-21 got the auto save of calculations working
    [2026_01_20,18_31_12 calculation_results.csv]
2026-01-21 Added all buck converter formulas
    [buck_converter.SchDoc]
2026-01-21 Added webench output for the buck converter
2026-01-21 got buck converter calculations to work with the save file
    [2026_01_20,20_43_53 calculation_results.csv]
2026-01-21 New calculation file
    [2026_01_20,18_31_12 calculation_results.csv, 2026_01_20,20_43_53 calculation_results.csv, 2026_01_20,20_46_05 calculation_results.csv]
2026-01-21 done buck converter schematic
    [2026_01_20,20_52_32 calculation_results.csv, 7435157.stp, CAP_GRM21_MUR.step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]
2026-01-21 Added more notes and silkscreen features
    [buck_converter.SchDoc, ldo_3v3.SchDoc, power_board_v0.PcbDoc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]
2026-01-21 got the rooms on the PCB file working
    [buck_converter.SchDoc, ldo_3v3.SchDoc, power_board.PrjPcb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]
2026-01-22 basic uart print example
2026-01-23 created the configs for adc and interrupts
2026-02-01 created motor board directory
2026-02-02 created the layout schematic for the controller perfboard
    [board.kicad_pcb, board.kicad_sch]
2026-02-19 tried workong with stm
    [2026_01_20,20_46_05 calculation_results.csv, 2026_01_20,20_52_32 calculation_results.csv, 7435157.stp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]
2026-02-20 added adc code to esp now code
2026-02-20 ADC values transmit from the controller to the bot of esp now, tested
2026-02-21 added PWM control code so that one motor can now be wirelessly controlled
2026-02-21 working wireless with steering
2026-03-22 added i2c
2026-03-22 forced i2c testing
2026-03-26 ultrasonic running with pwm
2026-03-26 transmits a few ultrasonics
2026-03-27 reliable control & ultrasonic transmission
2026-03-27 wireless transmission and display of ultrasonic
2026-03-30 Added wireless buzzer and headlight toggle
    [controller_modified_with_display.c, receiver_modified.c]

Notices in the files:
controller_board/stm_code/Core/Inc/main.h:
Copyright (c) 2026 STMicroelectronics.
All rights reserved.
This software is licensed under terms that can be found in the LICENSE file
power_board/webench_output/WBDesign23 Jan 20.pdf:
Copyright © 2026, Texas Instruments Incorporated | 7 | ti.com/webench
